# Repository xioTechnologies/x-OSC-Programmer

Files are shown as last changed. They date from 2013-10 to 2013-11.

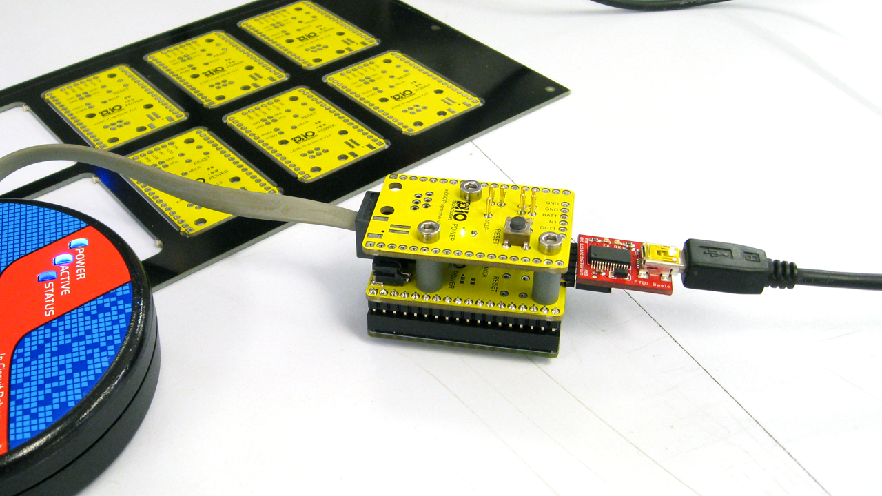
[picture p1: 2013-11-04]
Assembled.png

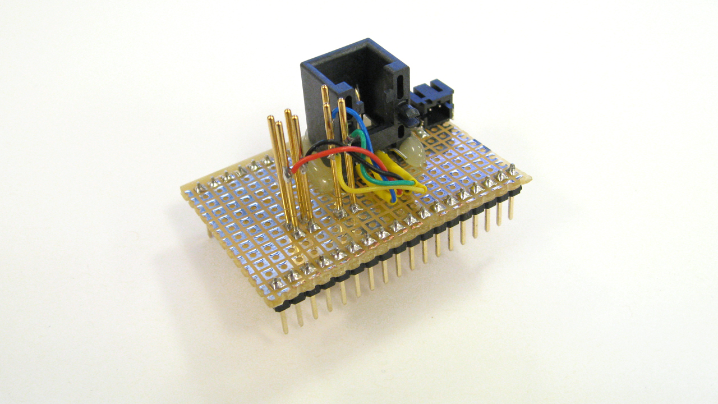
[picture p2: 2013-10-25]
Prototype.jpg

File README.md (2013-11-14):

x-OSC-Programmer
================

Adapter for programming [x-OSCs](http://www.x-io.co.uk/products/x-osc/) with ICSP.  Designed to be assembled from two copies of the PCB separated by three [spacers](http://uk.rs-online.com/web/p/round-spacers/2652192/) with the [reset button](http://uk.rs-online.com/web/p/tactile-switches/7831252/) and power LED mounted on the top board.  Electrical connections between the PCBs are made through the [pogo pins](https://www.sparkfun.com/products/9174).  Also features header for [FTDI USB serial converter](https://www.sparkfun.com/products/9716) which can also be used to power x-OSC via USB.

PCB with black solder mask and yellow silkscreen was ordered from [pcbpanel](http://www.pcbpanel.co.uk/browse-and-buy-pcb-panels.html?product_id=21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).

Fully Assembled
---------------

<div align="center">

</div>

<div align="center">

</div>

Prototype Design
----------------

<div align="center">

</div>

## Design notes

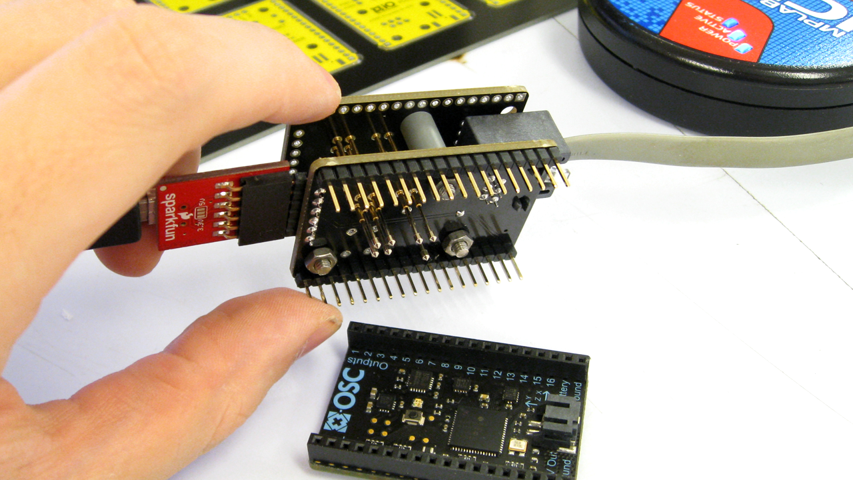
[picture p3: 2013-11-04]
Underside.png

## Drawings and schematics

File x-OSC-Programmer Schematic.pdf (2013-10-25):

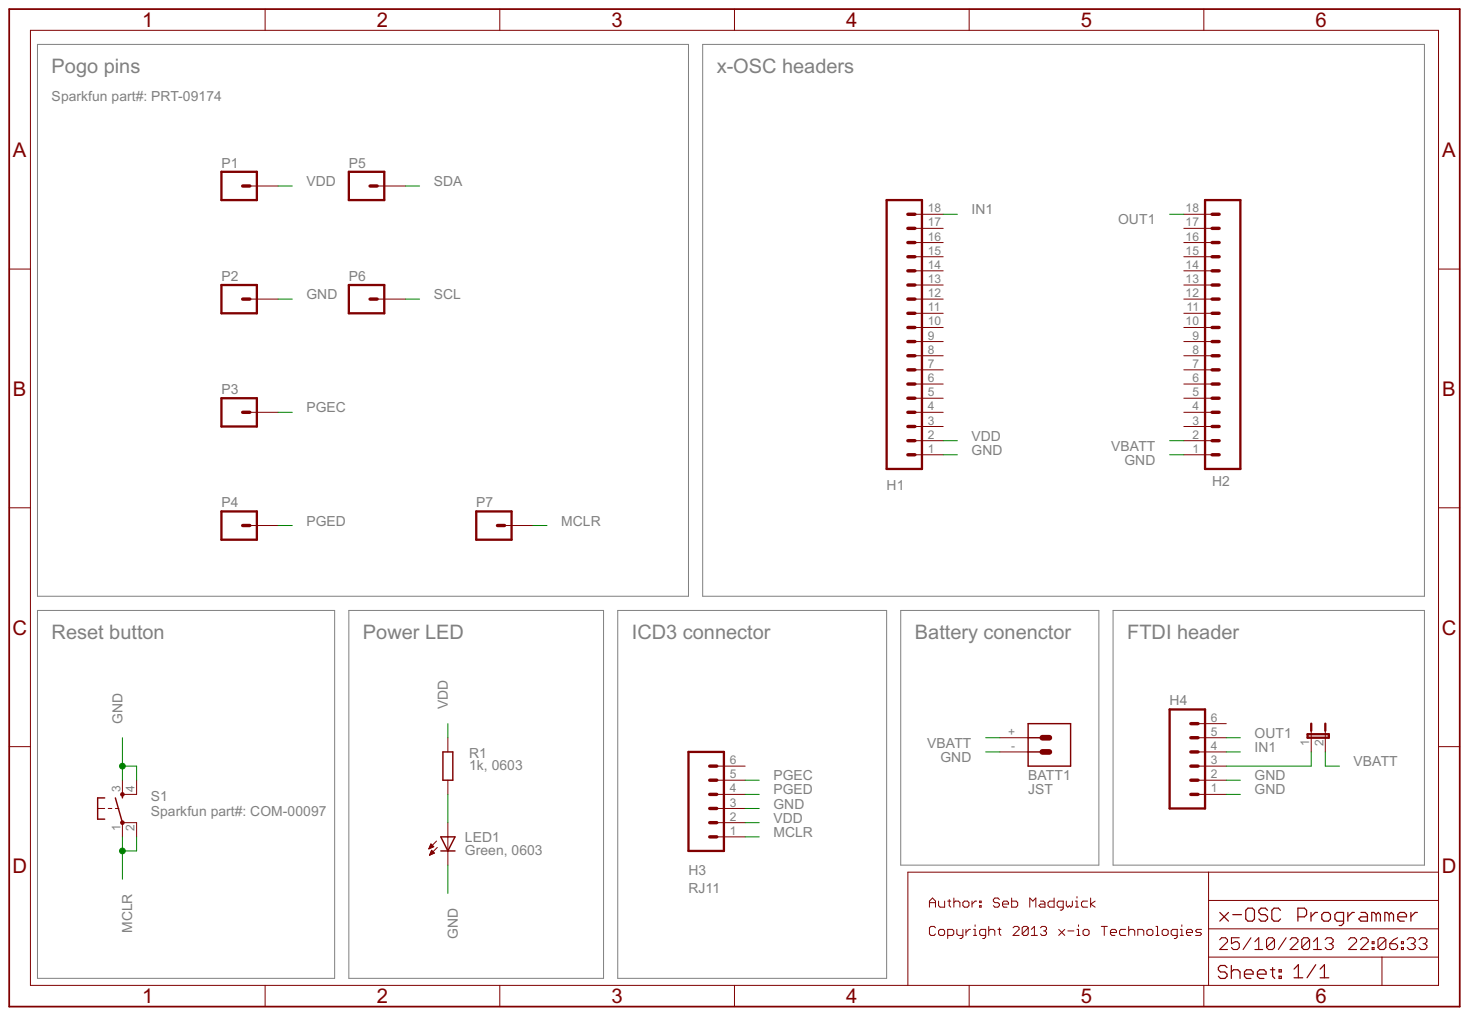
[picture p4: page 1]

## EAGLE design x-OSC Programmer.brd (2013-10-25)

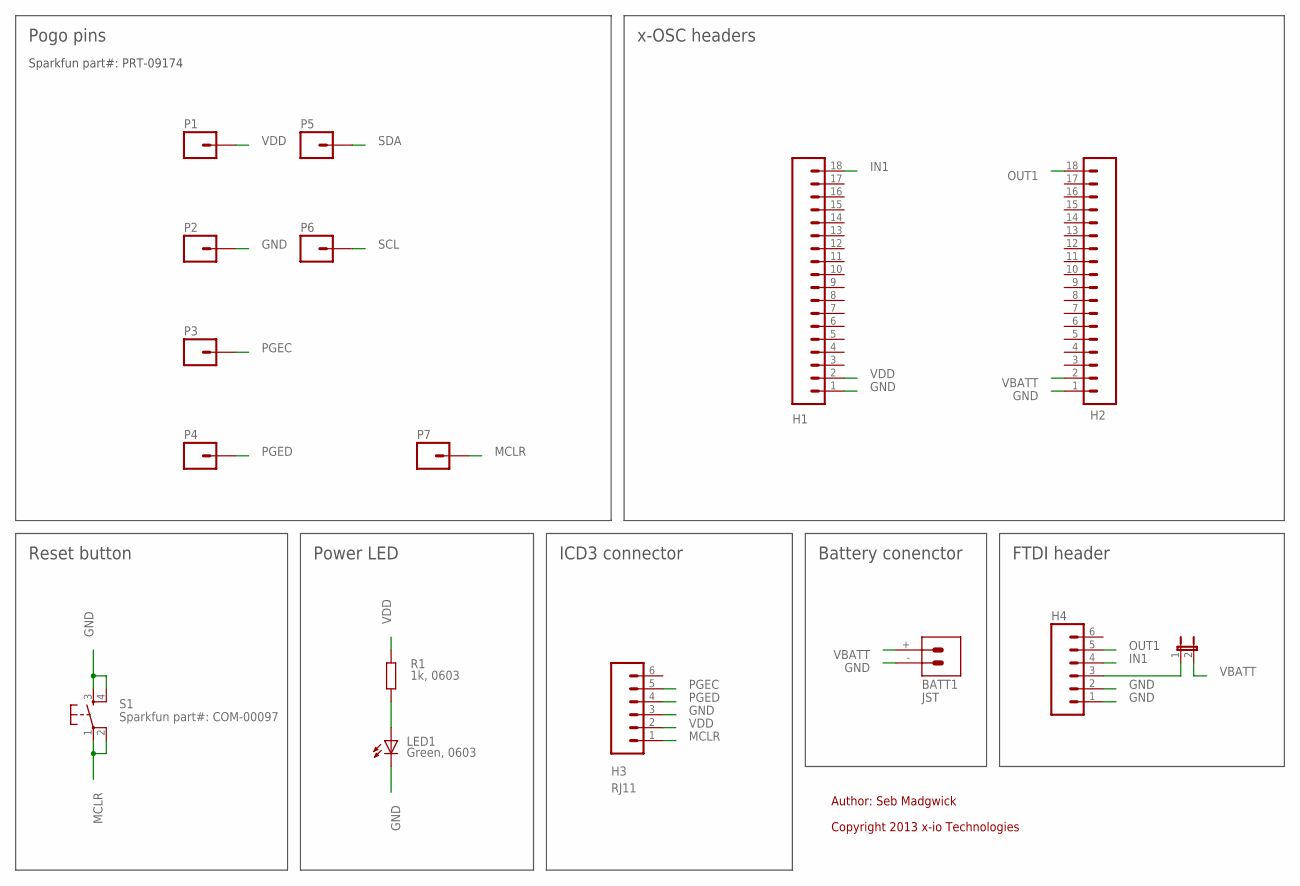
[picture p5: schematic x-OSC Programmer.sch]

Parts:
BATT1: JST; JST-R/A
H1, H2: M18_; 1X18
H3: RJ11; RJ11-6
H4: M06SIP; 1X06
JP1: JUMPER-2SMD-NO; SJ_2S-NO
LED1: Green, 0603; LED-0603
P1, P2, P3, P4, P5, P6, P7: M01PTH; 1X01
R1: 1k, 0603; R0402
S1: Sparkfun part#: COM-00097; TACTILE-PTH

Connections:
GND: BATT1.-, H1.1, H2.1, H3.3, H4.1, H4.2, LED1.C, P2.1, S1.3, S1.4
IN1: H1.18, H4.4
MCLR: H3.1, P7.1, S1.1, S1.2
unnamed: LED1.A, R1.2
unnamed: H4.3, JP1.1
OUT1: H2.18, H4.5
PGEC: H3.5, P3.1
PGED: H3.4, P4.1
SCL: P6.1
SDA: P5.1
VBATT: BATT1.+, H2.2, JP1.2
VDD: H1.2, H3.2, P1.1, R1.1

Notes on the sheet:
Copyright 2013 x-io Technologies
Author: Seb Madgwick
Pogo pins
Sparkfun part#: PRT-09174
x-OSC headers
Reset button
Power LED
Battery conenctor
ICD3 connector
FTDI header

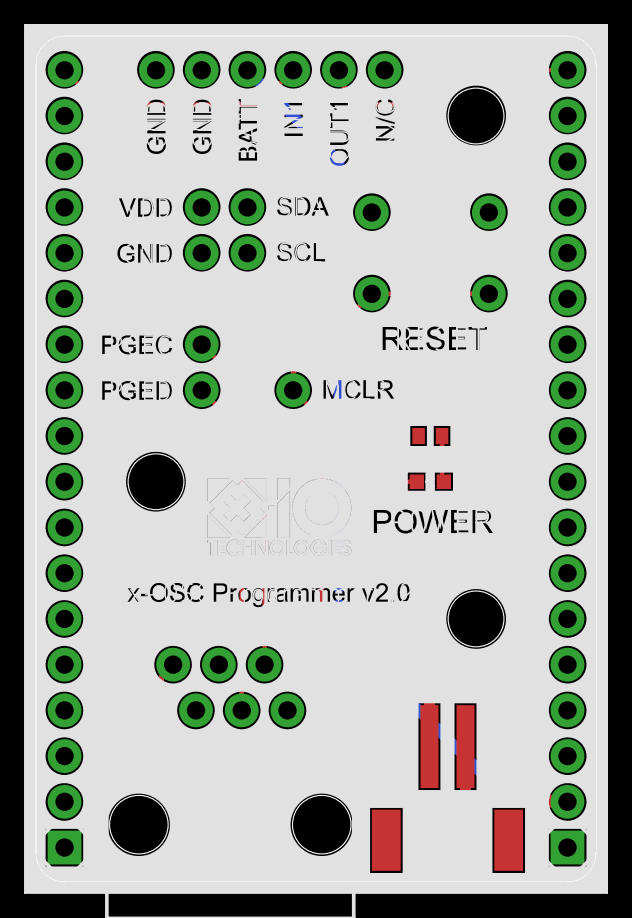
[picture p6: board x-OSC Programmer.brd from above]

Board: 2 copper layers, 31.1 x 47.0 mm, 18 parts (1 on the bottom side), 10 nets.

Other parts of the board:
U$1: X-IO_TECHNOLOGIES_LOGO_8MM_TOP
U$2: X-OSC_PROGRAMMER_V2.0_SILKSCREEN

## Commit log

2013-10-25 Redesign for x-OSC v1.3
    [x-OSC Programmer.brd, x-OSC Programmer.sch]
2013-10-25 Add photo of prototype
2013-10-25 Add FTDI header
    [x-OSC Programmer.brd, x-OSC Programmer.sch]
